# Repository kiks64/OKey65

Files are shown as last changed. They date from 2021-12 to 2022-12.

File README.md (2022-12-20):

# Okey65 ortholinear keyboard
<br />This work is licensed under a <a rel="license" href="http://creativecommons.org/licenses/by-nc-sa/4.0/">Creative Commons Attribution-NonCommercial-ShareAlike 4.0 International License</a>.
### _A 65 keys ortholinear keyboard using a qwerty based symetric layout_
<p align="center">
  
</p>  

The goal of this project is to design an enhanced version of my hand-wired keyboard that I have been using for several years. 
The keyboard has a well-balanced size that allows it to be quite compact while still having all the important keys available on the main layer.
Its layout is quite atypical but very convenient for typing text with accented Latin characters.  

It is based on an Atmega32u4 chip and runs QMK. The switch footprints are 5-pins MX type.
The design is minimalist, not including backlight, but modern : the pcb has no screws and is fully dampened by EVA foam.  
However, not being an electronics professional and this project being my first one, the switches are not hot-swappable since integrating this feature makes the design too complex for my skill level.  

Before continuing, I would like to thank ai03 and Masterzen for their tutorials which made this project possible, as well as all the contributors of the QMK firmware.
<p align="center">
  <br />
  
  &nbsp; &nbsp;
  
</p>
<p align="center">
  
</p>  

### List of required parts

The keyboard consists of a top plate, a pcb and a bottom plate, all in fr4 and designed on Kicad, as well as a 3d printed frame in resin 8000 (sla) designed on Fusion 360. All these parts were ordered from JLCPCB.
I chose these materials for their reasonable cost, their lightness as well as to obtain a soft typing feeling.   

All the electronic components come from Digikey except the Atmel chip which comes from Aliexpress since it is out of stock at all specialist retailers. The BOM list therefore consists of component references available from Digikey.  

Regarding the switches, I chose Gateron Pro Milky Yellow for their price, their softness and because they are stock lubed, which saves me laborious work.  

Finally, I reused the keycaps from my previous hand-wired keyboard because they come from Signature Plastics and are very expensive.
It is difficult to find a keyset that is perfectly compatible with this keyboard because the caps have to be non sculpted (dsa or xda) and ortholinear sets lack keycaps since they are designed for the Plank and Preonic which are smaller than my keyboard.  

Apart from the Signature Plastics solution, I found two sets that fit perfectly :   
A simple set, entirely white, inexpensive and available immediately: https://fr.aliexpress.com/item/1005003174191494.html (version white with legend)  
If you are not in a hurry, a magnificent set, more expensive and rarely available: https://drop.com/buy/massdrop-x-mito-canvas-xda-custom-keycap-set (alphas/betas set + text ortho/micons ortho set)  

**Aditionnal stuff you will need :**  
An USB type C cable.  
Spray paint and plastic primer : I used Montana Colors mtn94 paint, nice quality, easy to use.  
M2 brass standoffs 10mm : https://aliexpress.com/item/4000314663724.html (fit perfectly).  
M2 flat head screws 10mm : https://aliexpress.com/item/4001072025844.html  
Foam tapes 1x12mm + 3x8mm : https://aliexpress.com/item/33012825553.html  
Foam sheets  2mm : I used this item https://aliexpress.com/item/1005002856054113.html but it is more dense than I expected, maybe not the best option.  
A Double-sided adhesive tape.  
A syringe of solder paste (preferably T5 grade because the usb type c port is tricky to solder) as well as solder wire.  
A hot air rework station, a solder iron, tweezers, a magnifying glass and a cutting tool.  
A lot of patience :)  

### Assembly guide  

To start, heat the frame with a hair dryer and then insert the spacers into it. Once cool, the spacers will be tight enough, no need to add glue.  
Then take care of painting the frame and let it dry well.Sanding may be required before painting.  
Then place the 1mm adhesive foam strip inside the frame as shown in the photo below. 

Cut out the different foams using the top plate and bottom plate as templates :  
Between the top plate and the pcb I used 2 sheets of 2mm that I glued together before cutting them. With 4mm of compact foam for a space between plates of 3mm, soldering the switches was very difficult because I had to compress the foam at the same time. Instead, try to find a sheet of 3mm foam or less dense foam.  
Same observation for the foam between the pcb and the bottom plate, 4mm if good but EVA foam is definitely too dense and it was difficult to close the case the first time.  
A last sheet of 2mm foam glued under the bottom plate as a sole. Here, EVA is perfect and provides a good support for the keyboard and prevents the screw heads from touching the desk.  
Finally, cut strips of 3mm wide and thick self-adhesive foam and stick them all around the top plate.
<p align="center">
  <br />
  
  &nbsp; &nbsp;
  
</p>  

Now it's time to solder the components on the pcb.  
Leave the components in their bag until it is time to place them on the solder paste and be sure of their correct placement. Once out of their bag, it is very difficult to differentiate them so be careful!  
You will have 5 pcb, so also have some spare components in case it goes wrong. If you do not know how to use a hot air station, I advise you to find out before you start.  

Start with the usb receptacle which is the hardest part to solder because the pins are very close. Use very little solder paste to avoid making bridges which are very hard to see and remove.
Do not forget to secure the fixing of the usb receptacle by soldering the through tabs with a soldering iron and soldering wire  
Do the same for the Atmel chip, but this time it's easier and you can put a little more solder paste.  
Finally, put solder paste on all the remaining pads and arrange all your smd components, taking care to respect the polarity of the diodes, and solder them all at the same time.  

Check your welds with a magnifying glass and use a multimeter to check that there are no bridges.  
If everything is ok, it's time to flash the firmware. Instructions are available in the README file of the firmware's folder.  

Finally comes the step of soldering the switches, don't forget the foam between the top plate and the pcb ;)  
Start by soldering a switch at each corner, then one or two in the middle. After that, place all the switches and solder them.  

Plug in your keyboard to test all the keys. If a whole row or column does not work, check that all the pins of the chip are well soldered. If an isolated key does not work, it is likely that the polarities of the associated diode are reversed.  

If everything works, all you have to do is insert the assembly into the frame, add the 4mm foam, place the bottom plate and screw it gently.  
Finally install the caps, connect the usb cable and enjoy!  
If you plan to use accents, set your computer's input method to US International.
  <p align="center">
  <br />
  
  &nbsp; &nbsp;
  
</p>  
<p align="center">
  
  &nbsp; &nbsp;
  
</p>  

Using a wrist rest greatly improves comfort and ergonomics.
I made one with some EVA foam, double sided tape and cloth, the dimensions are 300x80x15mm and that's fine, a little longer would be perfect, like 320-350mm.

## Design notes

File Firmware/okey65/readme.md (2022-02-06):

# Okey65  

okey65  

A 65 keys ortholinear keyboard using a qwerty based symetric layout.  

Keyboard Maintainer: [Sylvain Lafourcade](https://github.com/kiks64)  
Hardware Supported: okey65  
Hardware Availability: https://github.com/kiks64/OKey65  

### Flashing procedure  

Set up your QMK build environment  
See the [build environment setup](https://docs.qmk.fm/#/getting_started_build_tools). Brand new to QMK? Start with our [Complete Newbs Guide](https://docs.qmk.fm/#/newbs).  

Add "okey65" folder to "keyboards" directory of QMK  

Enter the bootloader in 2 ways:  
Bootmagic reset**: Hold down the key at (0,0) in the matrix (the top left key) and plug in the keyboard  
Physical reset button**: Briefly press the button on the back of the PCB  
_Note that the first time you plug in the keyboard it automatically runs dfu mode, so you don't have to do anything._
 
Flash the keyboard using the GUI or by typing this CLI command from "qmk_firmware" directory :  

    qmk flash -kb okey65 -km default

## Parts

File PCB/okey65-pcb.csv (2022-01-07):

Id | Référence | Boîtier | Quantité | Désignation | Digikey
1 | FB1 | L_1206_3216Metric | 1 | 60@100MHz | FBMJ3216HM600-TV
3 | C7 | C_1206_3216Metric | 1 | 10uF | CL31B106KOHVPNE
4 | C3 | C_0805_2012Metric | 1 | 1uF | CL21B105KAFVPNE
5 | D68 | SOT143B | 1 | PRTR5V0U2X | PRTR5V0U2X,215
6 | F1 | Fuse_1206_3216Metric | 1 | 500mA | 0ZCJ0025AF2E
7 | Y1 | Crystal_SMD_3225-4Pin_3.2x2.5mm | 1 | 16MHz | ABM8-16.000MHZ-10-1-U-T
8 | U1 | TQFP-44_10x10mm_P0.8mm | 1 | ATmega32U4-AU
9 | SW1 | SKQG-1155865 | 1 | SW_Push | PTS526 SM15 SMTR2 LFS
10 | R8,R5 | R_0805_2012Metric | 2 | 150 | CRCW0805150RJNEAHP
11 | R7,R6 | R_0805_2012Metric | 2 | 5.1k | AC0805FR-075K1L
12 | R4,R1 | R_0805_2012Metric | 2 | 10k | AC0805FR-0710KL
13 | R3,R2 | R_0805_2012Metric | 2 | 22 | AC0805FR-0722RL
14 | J1 | USB_C_Receptacle_Palconn_UTC16-G | 1 | USB_C_Receptacle_USB2.0 | USB4105-GF-A-120
15 | D67,D66 | LED_1206_3216Metric_ReverseMount_Hole1.8x2.4mm | 2 | LED | LTST-C230KGKT
16 | D65,D64,D63,D62,D61,D60,D59,D58,D57,D56,D55,D54,D53,D52,D51,D50,D49,D48,D47,D46,D45,D44,D43,D42,D41,D40,D39,D38,D37,D36,D35,D34,D33,D32,D31,D30,D29,D28,D27,D26,D25,D24,D23,D22,D21,D20,D19,D18,D17,D16,D15,D14,D13,D12,D11,D10,D9,D8,D7,D6,D5,D4,D3,D2,D1 | D_SOD-123 | 65 | SOD-123 | BAV16W-7-F
17 | C6,C5,C4 | C_0805_2012Metric | 3 | 0.1uF | CL21B104KBF5PNE
18 | C2,C1 | C_0805_2012Metric | 2 | 22pF | CL21C220JB61PNC

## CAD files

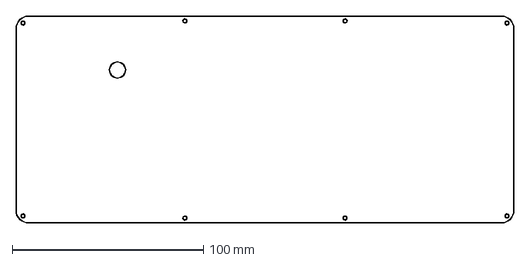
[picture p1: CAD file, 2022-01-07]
Bottom Plate/bottom-plate-edge-cut.dxf
260.6 x 108.3 mm

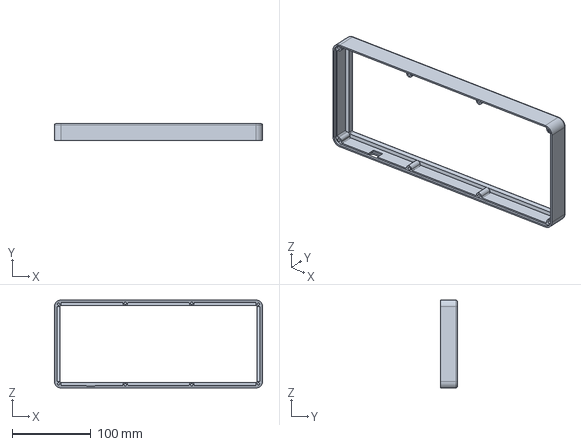
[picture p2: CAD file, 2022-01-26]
Frame/Frame.step
263.7 x 21.5 x 111.3 mm

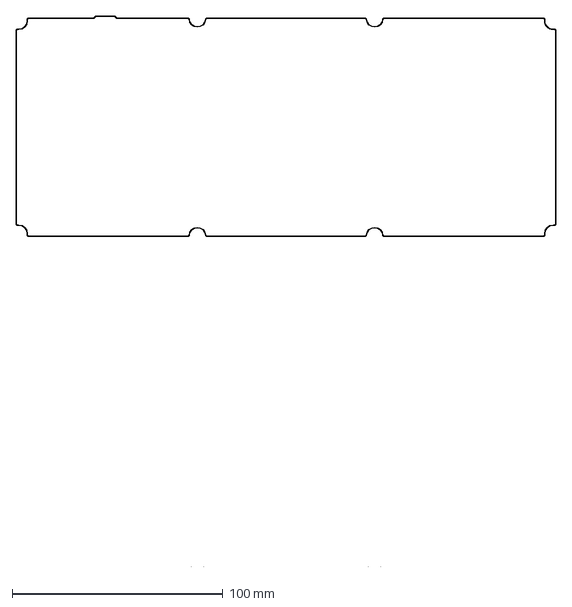
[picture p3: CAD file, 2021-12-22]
PCB/pcb-edge-cut.dxf
255.7 x 261.0 mm

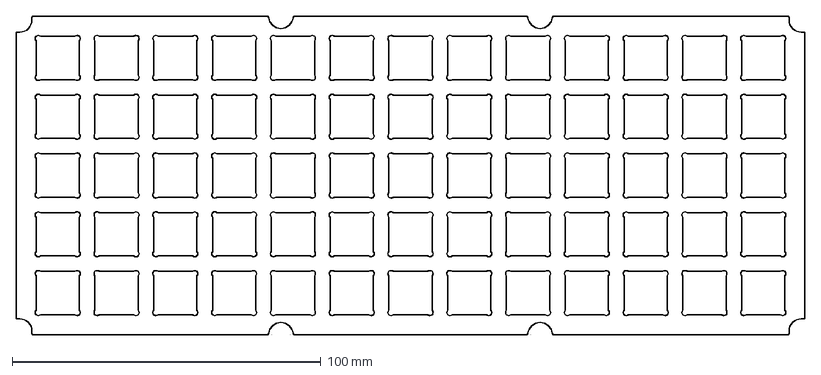
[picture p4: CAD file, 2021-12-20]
Top Plate/top-plate-edge-cut.dxf
255.7 x 103.3 mm

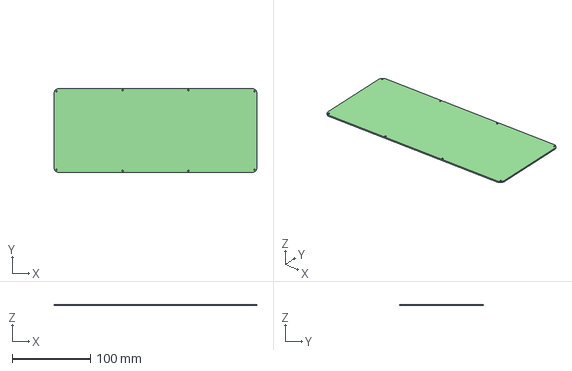
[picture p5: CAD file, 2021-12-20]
Bottom Plate/okey65-bottom-plate.step
259.6 x 107.2 x 1.60 mm

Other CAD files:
Frame/Frame.3mf
Frame/Frame.stl

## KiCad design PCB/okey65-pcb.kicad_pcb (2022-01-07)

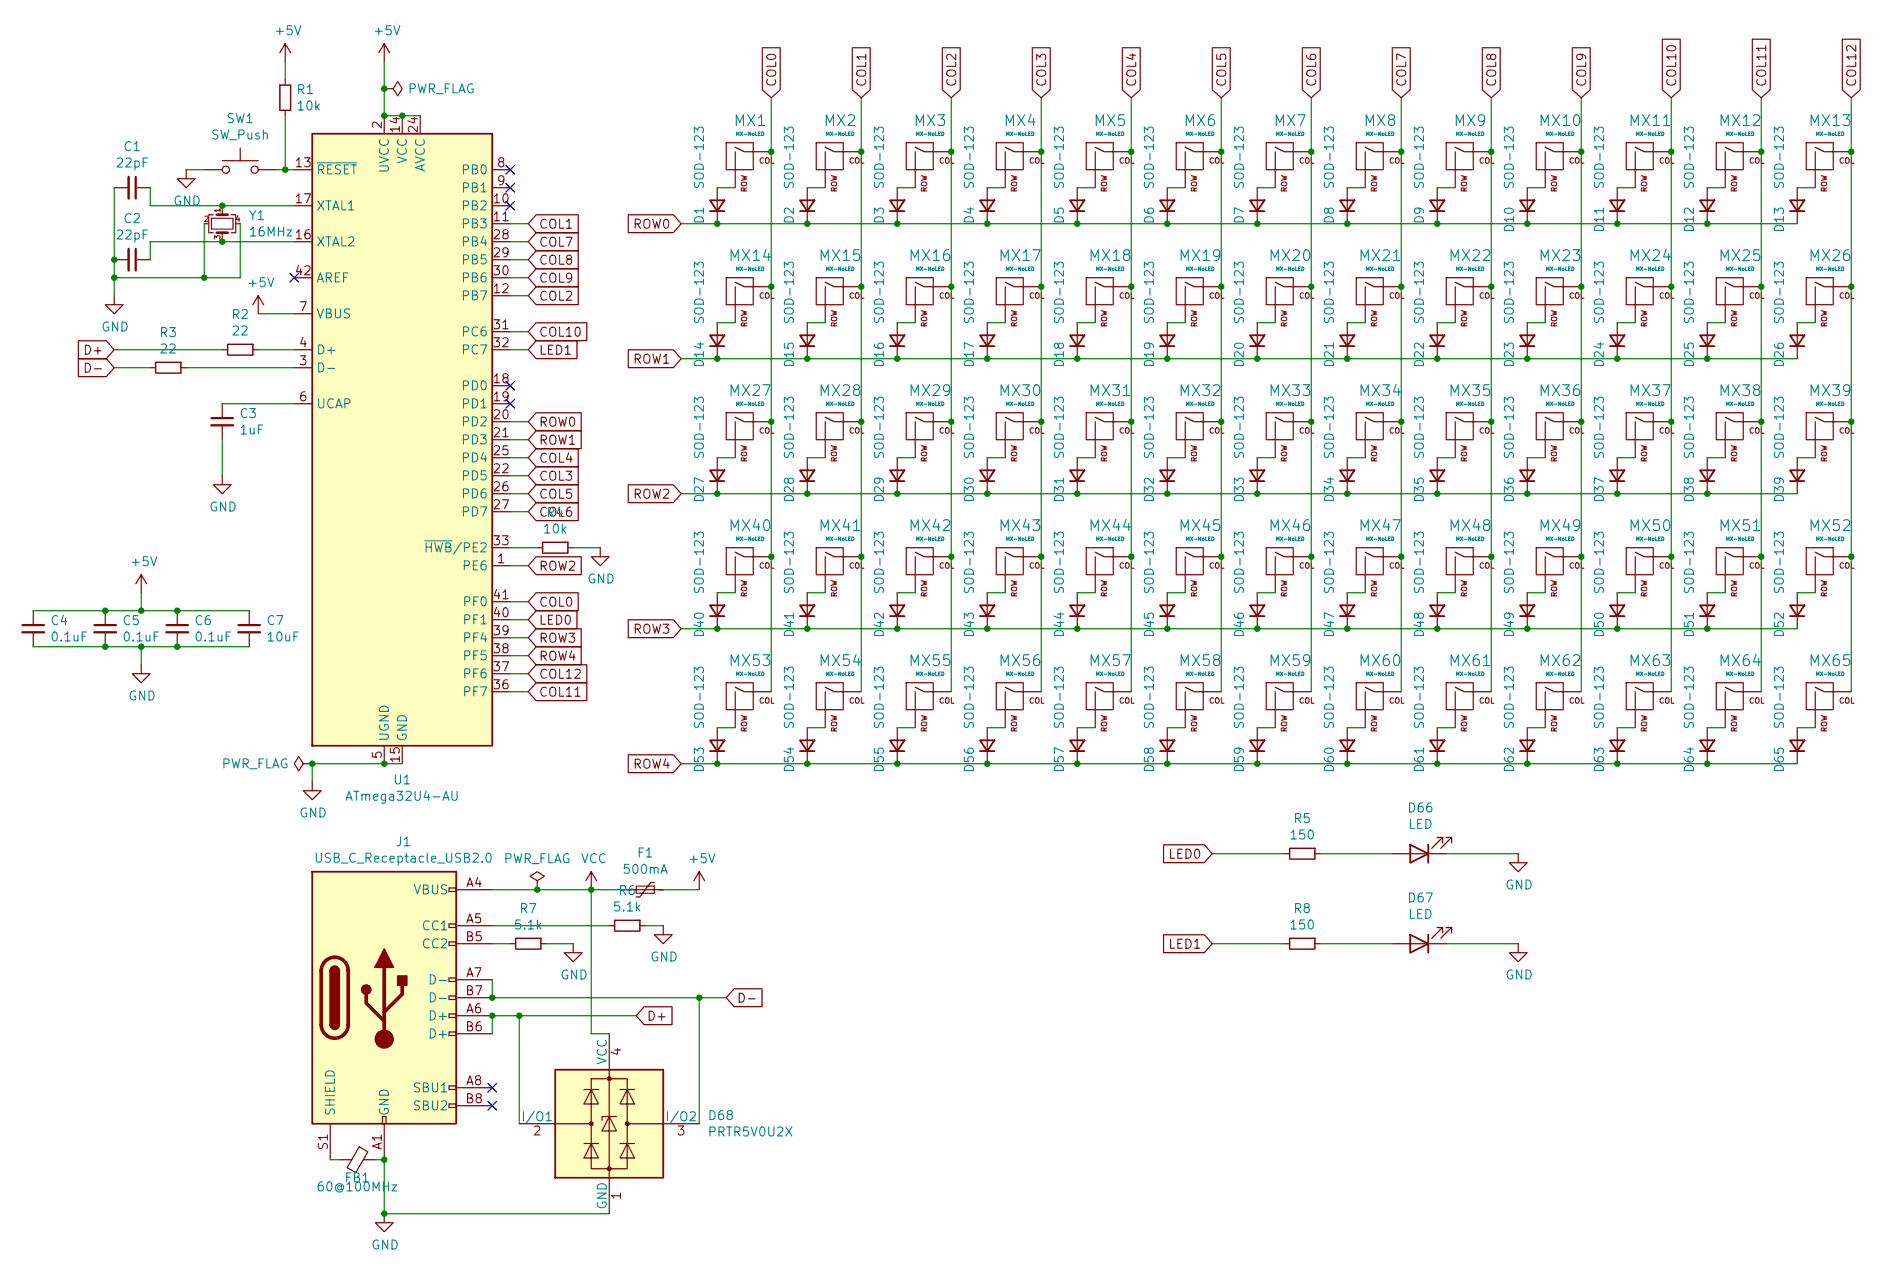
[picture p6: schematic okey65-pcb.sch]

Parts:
C1, C2: 22pF; C_0805_2012Metric
C3: 1uF; C_0805_2012Metric
C4, C5, C6: 0.1uF; C_0805_2012Metric
C7: 10uF; C_1206_3216Metric
D1, D2, D3, D4, D5, D6, D7, D8, D9, D10, D11, D12, D13, D14, D15, D16, D17, D18, D19, D20, D21, D22, D23, D24, D25, D26, D27, D28, D29, D30, D31, D32, D33, D34, D35, D36, D37, D38, D39, D40, D41, D42, D43, D44, D45, D46, D47, D48, D49, D50, D51, D52, D53, D54, D55, D56, D57, D58, D59, D60, D61, D62, D63, D64, D65: SOD-123; D_SOD-123
D66, D67: LED; LED_1206_3216Metric_ReverseMount_Hole1.8x2.4mm
D68: PRTR5V0U2X; SOT143B
F1: 500mA; Fuse_1206_3216Metric
FB1: 60@100MHz; L_1206_3216Metric
J1: USB_C_Receptacle_USB2.0; USB_C_Receptacle_Palconn_UTC16-G
MX1, MX2, MX3, MX4, MX5, MX6, MX7, MX8, MX9, MX10, MX11, MX12, MX13, MX14, MX15, MX16, MX17, MX18, MX19, MX20, MX21, MX22, MX23, MX24, MX25, MX26, MX27, MX28, MX29, MX30, MX31, MX32, MX33, MX34, MX35, MX36, MX37, MX38, MX39, MX40, MX41, MX42, MX43, MX44, MX45, MX46, MX47, MX48, MX49, MX50, MX51, MX52, MX53, MX54, MX55, MX56, MX57, MX58, MX59, MX60, MX61, MX62, MX63, MX64, MX65: MX-NoLED; MXOnly-1U-NoLED
R1, R4: 10k; R_0805_2012Metric
R2, R3: 22; R_0805_2012Metric
R5, R8: 150; R_0805_2012Metric
R6, R7: 5.1k; R_0805_2012Metric
SW1: SW_Push; SKQG-1155865
U1: ATmega32U4-AU; TQFP-44_10x10mm_P0.8mm
Y1: 16MHz; Crystal_SMD_3225-4Pin_3.2x2.5mm

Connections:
+5V: C4.1, C5.1, C6.1, C7.1, F1.1, R1.1, U1.2 (UVCC), U1.7 (VBUS), U1.14 (VCC), U1.24 (AVCC), U1.34 (VCC), U1.44 (AVCC)
COL0: MX1.1 (COL), MX14.1 (COL), MX27.1 (COL), MX40.1 (COL), MX53.1 (COL), U1.41 (PF0)
COL1: MX2.1 (COL), MX15.1 (COL), MX28.1 (COL), MX41.1 (COL), MX54.1 (COL), U1.11 (PB3)
COL2: MX3.1 (COL), MX16.1 (COL), MX29.1 (COL), MX42.1 (COL), MX55.1 (COL), U1.12 (PB7)
COL3: MX4.1 (COL), MX17.1 (COL), MX30.1 (COL), MX43.1 (COL), MX56.1 (COL), U1.22 (PD5)
COL4: MX5.1 (COL), MX18.1 (COL), MX31.1 (COL), MX44.1 (COL), MX57.1 (COL), U1.25 (PD4)
COL5: MX6.1 (COL), MX19.1 (COL), MX32.1 (COL), MX45.1 (COL), MX58.1 (COL), U1.26 (PD6)
COL6: MX7.1 (COL), MX20.1 (COL), MX33.1 (COL), MX46.1 (COL), MX59.1 (COL), U1.27 (PD7)
COL7: MX8.1 (COL), MX21.1 (COL), MX34.1 (COL), MX47.1 (COL), MX60.1 (COL), U1.28 (PB4)
COL8: MX9.1 (COL), MX22.1 (COL), MX35.1 (COL), MX48.1 (COL), MX61.1 (COL), U1.29 (PB5)
COL9: MX10.1 (COL), MX23.1 (COL), MX36.1 (COL), MX49.1 (COL), MX62.1 (COL), U1.30 (PB6)
COL10: MX11.1 (COL), MX24.1 (COL), MX37.1 (COL), MX50.1 (COL), MX63.1 (COL), U1.31 (PC6)
COL11: MX12.1 (COL), MX25.1 (COL), MX38.1 (COL), MX51.1 (COL), MX64.1 (COL), U1.36 (PF7)
COL12: MX13.1 (COL), MX26.1 (COL), MX39.1 (COL), MX52.1 (COL), MX65.1 (COL), U1.37 (PF6)
D+: D68.2 (I/O1), J1.A6 (D+), J1.B6 (D+), R2.2
D-: D68.3 (I/O2), J1.A7 (D-), J1.B7 (D-), R3.2
GND: C1.2, C2.2, C3.2, C4.2, C5.2, C6.2, C7.2, D66.1 (K), D67.1 (K), D68.1 (GND), FB1.1, J1.A1 (GND), J1.A12 (GND), J1.B1 (GND), J1.B12 (GND), R4.1, R6.1, R7.1, SW1.1, U1.5 (UGND), U1.15 (GND), U1.23 (GND), U1.35 (GND), U1.43 (GND), Y1.2, Y1.4
LED0: R5.2, U1.40 (PF1)
LED1: R8.2, U1.32 (PC7)
unnamed: C1.1, U1.17 (XTAL1), Y1.1
unnamed: C2.1, U1.16 (XTAL2), Y1.3
unnamed: C3.1, U1.6 (UCAP)
unnamed: D1.2 (A), MX1.2 (ROW)
unnamed: D2.2 (A), MX2.2 (ROW)
unnamed: D3.2 (A), MX3.2 (ROW)
unnamed: D4.2 (A), MX4.2 (ROW)
unnamed: D5.2 (A), MX5.2 (ROW)
unnamed: D6.2 (A), MX6.2 (ROW)
unnamed: D7.2 (A), MX7.2 (ROW)
unnamed: D8.2 (A), MX8.2 (ROW)
unnamed: D9.2 (A), MX9.2 (ROW)
unnamed: D10.2 (A), MX10.2 (ROW)
unnamed: D11.2 (A), MX11.2 (ROW)
unnamed: D12.2 (A), MX12.2 (ROW)
unnamed: D13.2 (A), MX13.2 (ROW)
unnamed: D14.2 (A), MX14.2 (ROW)
unnamed: D15.2 (A), MX15.2 (ROW)
unnamed: D16.2 (A), MX16.2 (ROW)
unnamed: D17.2 (A), MX17.2 (ROW)
unnamed: D18.2 (A), MX18.2 (ROW)
unnamed: D19.2 (A), MX19.2 (ROW)
unnamed: D20.2 (A), MX20.2 (ROW)
unnamed: D21.2 (A), MX21.2 (ROW)
unnamed: D22.2 (A), MX22.2 (ROW)
unnamed: D23.2 (A), MX23.2 (ROW)
unnamed: D24.2 (A), MX24.2 (ROW)
unnamed: D25.2 (A), MX25.2 (ROW)
unnamed: D26.2 (A), MX26.2 (ROW)
unnamed: D27.2 (A), MX27.2 (ROW)
unnamed: D28.2 (A), MX28.2 (ROW)
unnamed: D29.2 (A), MX29.2 (ROW)
unnamed: D30.2 (A), MX30.2 (ROW)
unnamed: D31.2 (A), MX31.2 (ROW)
unnamed: D32.2 (A), MX32.2 (ROW)
unnamed: D33.2 (A), MX33.2 (ROW)
unnamed: D34.2 (A), MX34.2 (ROW)
unnamed: D35.2 (A), MX35.2 (ROW)
unnamed: D36.2 (A), MX36.2 (ROW)
unnamed: D37.2 (A), MX37.2 (ROW)
unnamed: D38.2 (A), MX38.2 (ROW)
unnamed: D39.2 (A), MX39.2 (ROW)
unnamed: D40.2 (A), MX40.2 (ROW)
unnamed: D41.2 (A), MX41.2 (ROW)
unnamed: D42.2 (A), MX42.2 (ROW)
unnamed: D43.2 (A), MX43.2 (ROW)
unnamed: D44.2 (A), MX44.2 (ROW)
unnamed: D45.2 (A), MX45.2 (ROW)
unnamed: D46.2 (A), MX46.2 (ROW)
unnamed: D47.2 (A), MX47.2 (ROW)
unnamed: D48.2 (A), MX48.2 (ROW)
unnamed: D49.2 (A), MX49.2 (ROW)
unnamed: D50.2 (A), MX50.2 (ROW)
unnamed: D51.2 (A), MX51.2 (ROW)
unnamed: D52.2 (A), MX52.2 (ROW)
unnamed: D53.2 (A), MX53.2 (ROW)
unnamed: D54.2 (A), MX54.2 (ROW)
unnamed: D55.2 (A), MX55.2 (ROW)
unnamed: D56.2 (A), MX56.2 (ROW)
unnamed: D57.2 (A), MX57.2 (ROW)
unnamed: D58.2 (A), MX58.2 (ROW)
unnamed: D59.2 (A), MX59.2 (ROW)
unnamed: D60.2 (A), MX60.2 (ROW)
unnamed: D61.2 (A), MX61.2 (ROW)
unnamed: D62.2 (A), MX62.2 (ROW)
unnamed: D63.2 (A), MX63.2 (ROW)
unnamed: D64.2 (A), MX64.2 (ROW)
unnamed: D65.2 (A), MX65.2 (ROW)
unnamed: D66.2 (A), R5.1
unnamed: D67.2 (A), R8.1
unnamed: FB1.2, J1.S1 (SHIELD)
unnamed: J1.A5 (CC1), R6.2
unnamed: J1.B5 (CC2), R7.2
unnamed: R1.2, SW1.2, U1.13 (~RESET)
unnamed: R2.1, U1.4 (D+)
unnamed: R3.1, U1.3 (D-)
unnamed: R4.2, U1.33 (~HWB~/PE2)
ROW0: D1.1 (K), D2.1 (K), D3.1 (K), D4.1 (K), D5.1 (K), D6.1 (K), D7.1 (K), D8.1 (K), D9.1 (K), D10.1 (K), D11.1 (K), D12.1 (K), D13.1 (K), U1.20 (PD2)
ROW1: D14.1 (K), D15.1 (K), D16.1 (K), D17.1 (K), D18.1 (K), D19.1 (K), D20.1 (K), D21.1 (K), D22.1 (K), D23.1 (K), D24.1 (K), D25.1 (K), D26.1 (K), U1.21 (PD3)
ROW2: D27.1 (K), D28.1 (K), D29.1 (K), D30.1 (K), D31.1 (K), D32.1 (K), D33.1 (K), D34.1 (K), D35.1 (K), D36.1 (K), D37.1 (K), D38.1 (K), D39.1 (K), U1.1 (PE6)
ROW3: D40.1 (K), D41.1 (K), D42.1 (K), D43.1 (K), D44.1 (K), D45.1 (K), D46.1 (K), D47.1 (K), D48.1 (K), D49.1 (K), D50.1 (K), D51.1 (K), D52.1 (K), U1.39 (PF4)
ROW4: D53.1 (K), D54.1 (K), D55.1 (K), D56.1 (K), D57.1 (K), D58.1 (K), D59.1 (K), D60.1 (K), D61.1 (K), D62.1 (K), D63.1 (K), D64.1 (K), D65.1 (K), U1.38 (PF5)
VCC: D68.4 (VCC), F1.2, J1.A4 (VBUS), J1.A9 (VBUS), J1.B4 (VBUS), J1.B9 (VBUS)

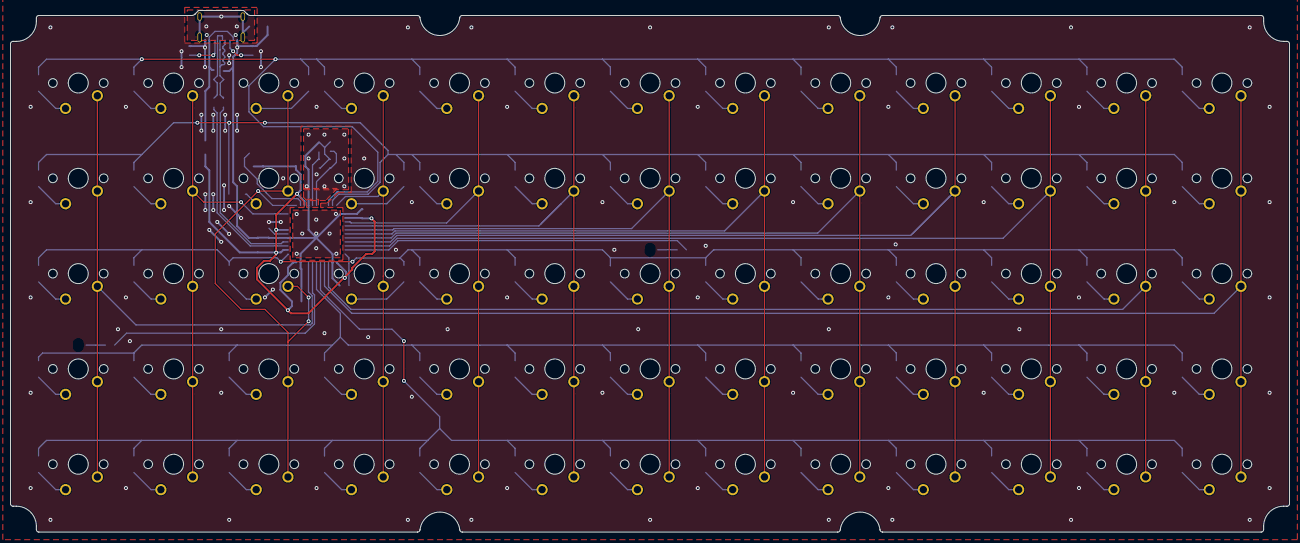
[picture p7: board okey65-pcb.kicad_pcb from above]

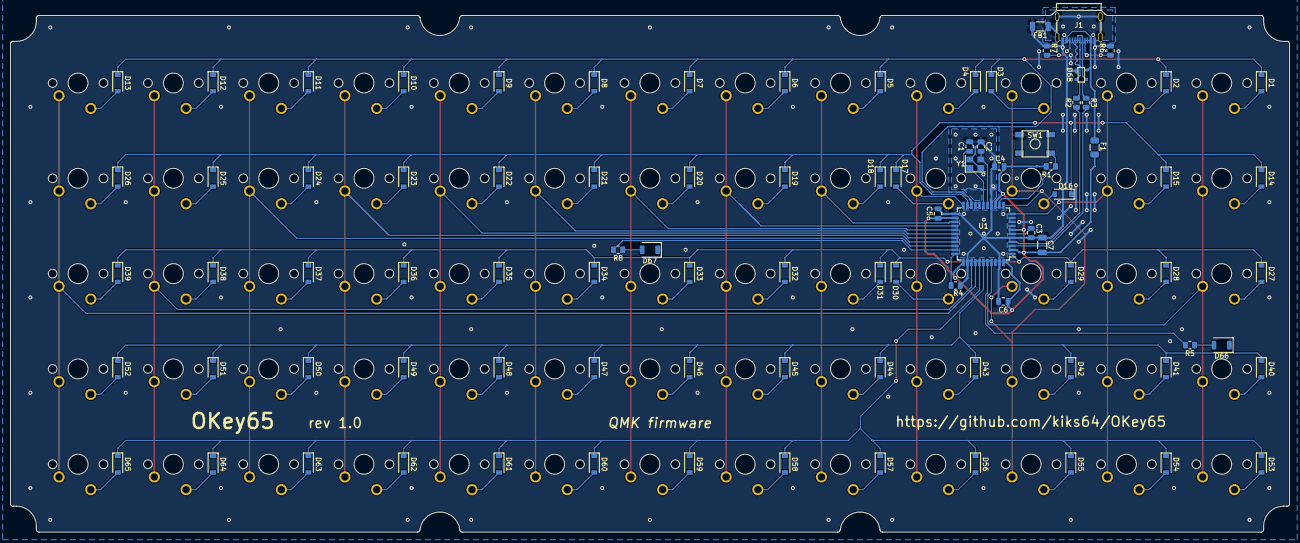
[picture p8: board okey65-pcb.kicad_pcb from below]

Board: 2 copper layers, 255.7 x 104.3 mm, 154 parts (89 on the bottom side), 102 nets.

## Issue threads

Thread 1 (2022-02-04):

Indicator LEDs for lock keys not working

kiks64, 2022-02-04:

Closed 2022-02-06.

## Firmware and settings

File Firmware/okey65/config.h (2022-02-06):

// Copyright 2022 Sylvain Lafourcade @kiks64
// SPDX-License-Identifier: GPL-2.0-or-later

#pragma once

#include "config_common.h"

#define VENDOR_ID    0xFEED
#define PRODUCT_ID   0x0000
#define DEVICE_VER   0x0001
#define MANUFACTURER kiks64
#define PRODUCT      okey65

#define MATRIX_ROWS 5
#define MATRIX_COLS 13

#define MATRIX_ROW_PINS { D2, D3, E6, F4, F5 }
#define MATRIX_COL_PINS { F0, B3, B7, D5, D4, D6, D7, B4, B5, B6, C6, F7, F6 }
#define UNUSED_PINS

#define DIODE_DIRECTION COL2ROW

#define LED_CAPS_LOCK_PIN F1
#define LED_SCROLL_LOCK_PIN C7
#define LED_PIN_ON_STATE 1

/* Debounce reduces chatter (unintended double-presses) - set 0 if debouncing is not needed */
#define DEBOUNCE 5

/* Mechanical locking support. Use KC_LCAP, KC_LNUM or KC_LSCR instead in keymap */
//#define LOCKING_SUPPORT_ENABLE
/* Locking resynchronize hack */
//#define LOCKING_RESYNC_ENABLE

/* If defined, GRAVE_ESC will always act as ESC when CTRL is held.
 * This is useful for the Windows task manager shortcut (ctrl+shift+esc).
 */
//#define GRAVE_ESC_CTRL_OVERRIDE

/*
 * Force NKRO
 *
 * Force NKRO (nKey Rollover) to be enabled by default, regardless of the saved
 * state in the bootmagic EEPROM settings. (Note that NKRO must be enabled in the
 * makefile for this to work.)
 *
 * If forced on, NKRO can be disabled via magic key (default = LShift+RShift+N)
 * until the next keyboard reset.
 *
 * NKRO may prevent your keystrokes from being detected in the BIOS, but it is
 * fully operational during normal computer usage.
 *
 * For a less heavy-handed approach, enable NKRO via magic key (LShift+RShift+N)
 * or via bootmagic (hold SPACE+N while plugging in the keyboard). Once set by
 * bootmagic, NKRO mode will always be enabled until it is toggled again during a
 * power-up.
 *
 */
#define FORCE_NKRO

/*
 * Feature disable options
 *  These options are also useful to firmware size reduction.
 */

/* disable debug print */
//#define NO_DEBUG

/* disable print */
//#define NO_PRINT

/* disable action features */
//#define NO_ACTION_LAYER
//#define LAYER_STATE_8BIT
//#define NO_ACTION_TAPPING
//#define NO_ACTION_ONESHOT


/* disable these deprecated features by default */
#define NO_ACTION_MACRO
#define NO_ACTION_FUNCTION

/* Bootmagic Lite key configuration */
#define BOOTMAGIC_LITE_ROW 0
#define BOOTMAGIC_LITE_COLUMN 0

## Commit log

2021-12-14 Initialize project
    [okey65-pcb.kicad_pcb, okey65-pcb.sch]
2021-12-14 Add PCB footprint libraries
2021-12-14 MCU circuit shematic
    [okey65-pcb.sch]
2021-12-14 USB circuit shematic
    [okey65-pcb.sch]
2021-12-14 Shema completed + pcb matrix
    [okey65-pcb.sch]
2021-12-15 Place all footprints
    [okey65-pcb.kicad_pcb]
2021-12-15 Route core circuits
    [okey65-pcb.kicad_pcb]
2021-12-16 Routing complete
    [okey65-pcb.kicad_pcb, okey65-pcb.sch]
2021-12-17 PCB complete
    [okey65-pcb-B_Cu.gbr, okey65-pcb-B_Mask.gbr, okey65-pcb-B_Paste.gbr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]
2021-12-20 Hardware almost complete
    [Frame.step, bottom-plate-edge-cut.dxf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]
2021-12-22 General improvements - no ground planes
    [Frame.step, okey65-pcb.kicad_pcb, okey65-pcb.sch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]
2022-01-07 v 1.0
    [bottom-plate-edge-cut.dxf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]
2022-01-26 Firmware complete
    Adding firmware + fixing a small issue with the frame
    [Frame.3mf, Frame.step, Frame.stl]
2022-02-03 Firmware update
    Update firmware (macros) and firmware README.
    [Frame.3mf, Frame.step, Frame.stl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]
2022-02-06 Firmware update
    Indicator LEDs issue fixed by rewriting the firmware with the officlal QMK environment instead of using kbfirmware.com configurator.
    [config.h]
